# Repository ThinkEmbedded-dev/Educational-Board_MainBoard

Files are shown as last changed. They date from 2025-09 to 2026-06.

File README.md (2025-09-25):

# ThinkEmbeded Base Sensor Board
The ThinkEmbeded Base Sensor Board is a versatile sensor board designed for various embedded applications. 
It features multiple sensors, including temperature, humidity, light, accelerometer, and more, making it ideal for IoT projects, environmental monitoring, and data logging.

## Features
- Multiple integrated sensors (temperature, humidity, light, accelerometer, etc.)
- Compact and lightweight design
- Easy to interface with Nucleo boards
- Supports I2C and SPI external connections
- Onboard power regulation
- Extended by additional sheild for IoT connectivity and AI capabilities

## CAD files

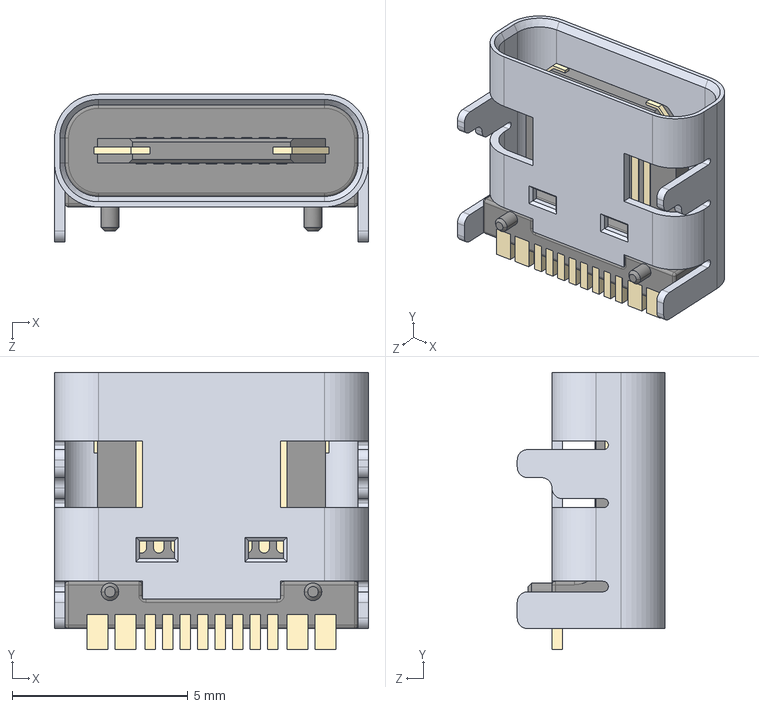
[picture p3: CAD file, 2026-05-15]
Libreries/3D Models/usb-c.STEP
8.94 x 7.90 x 4.20 mm

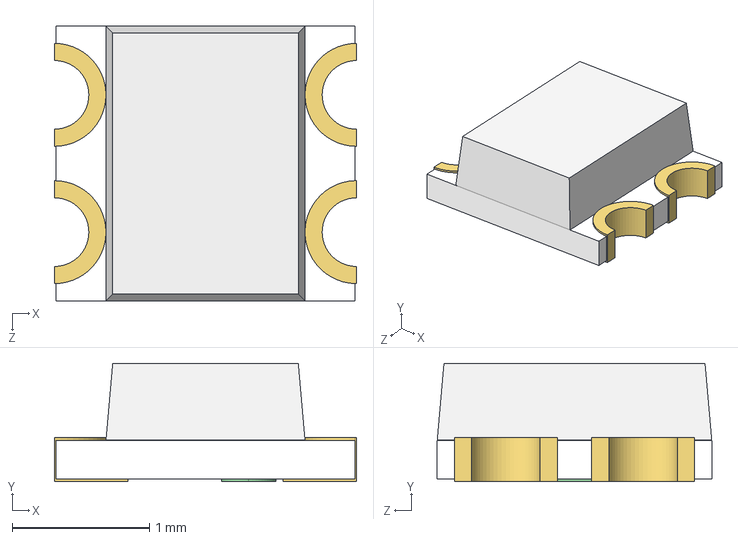
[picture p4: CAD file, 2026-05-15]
Libreries/3D Models/WS2812-2020.STEP
2.20 x 0.86 x 2.00 mm

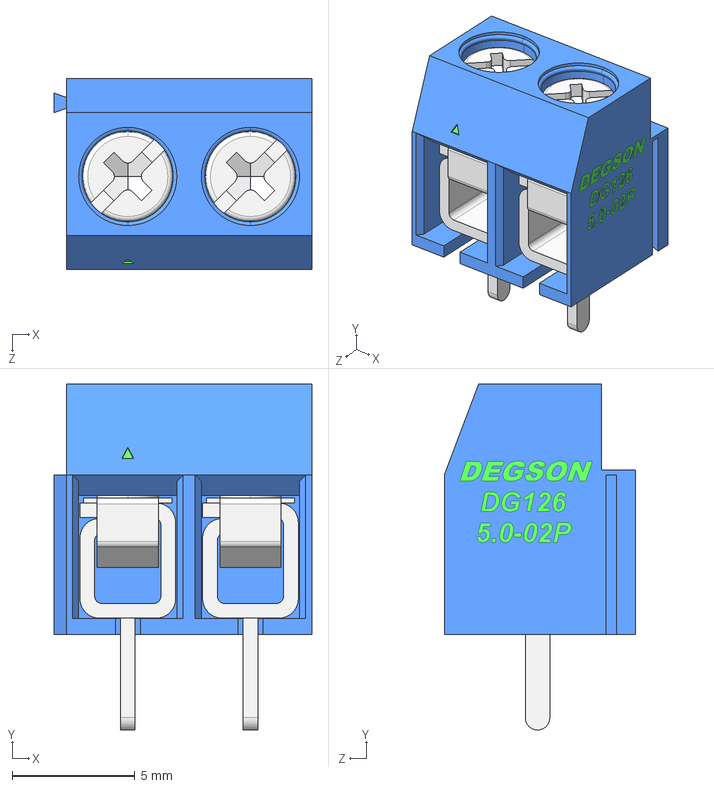
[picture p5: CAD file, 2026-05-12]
Libreries/3D Models/DG126-5.0-02P-12-00AH.STEP
10.5 x 14.1 x 7.80 mm

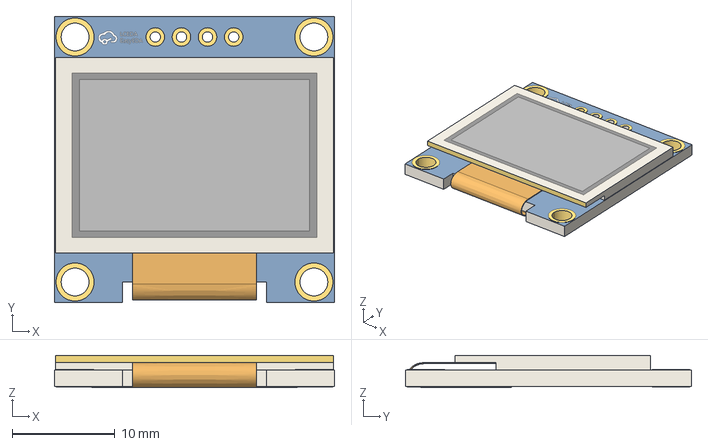
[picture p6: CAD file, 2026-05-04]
Libreries/3D Models/HS96L03W2C03 DISPLAY.step
27.2 x 27.8 x 3.12 mm

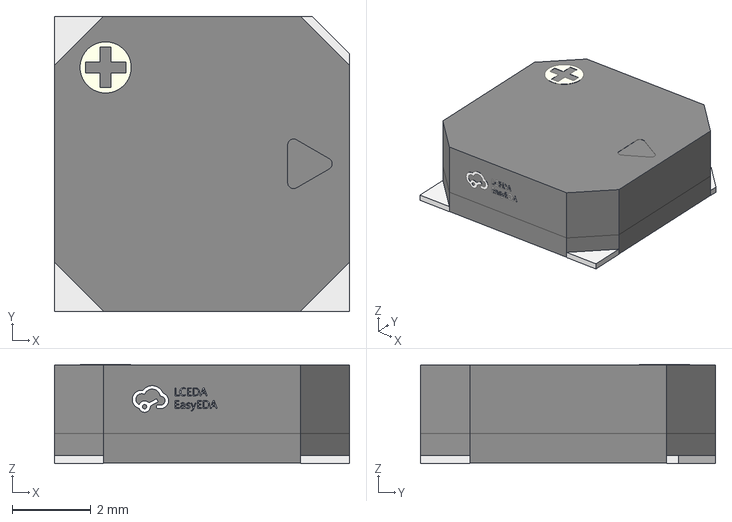
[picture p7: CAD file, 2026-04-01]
Libreries/3D Models/buzzer.step
7.50 x 7.51 x 2.52 mm

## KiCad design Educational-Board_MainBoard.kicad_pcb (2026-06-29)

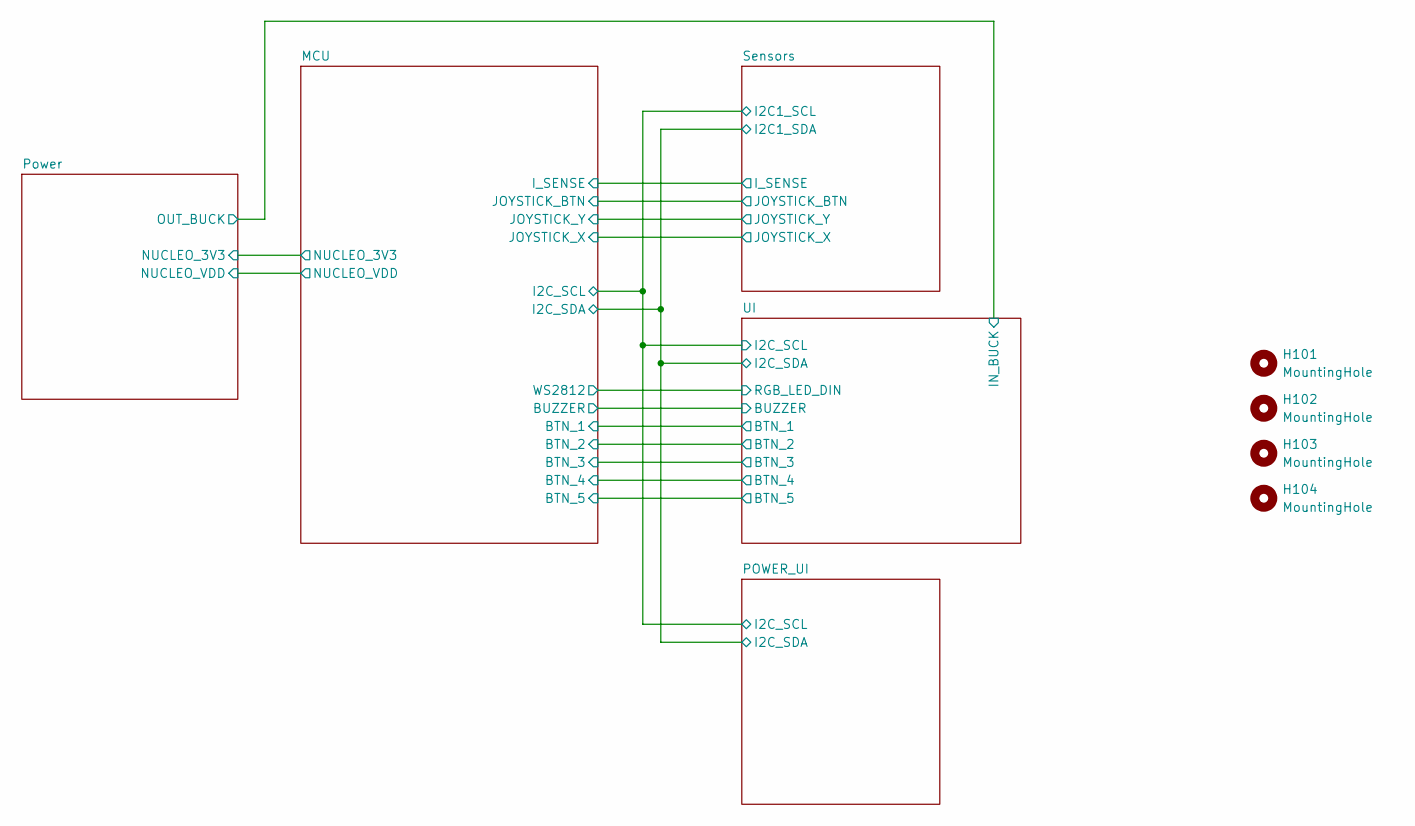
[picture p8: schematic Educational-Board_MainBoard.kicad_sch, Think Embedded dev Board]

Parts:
H101, H102, H103, H104: MountingHole; MountingHole_3.2mm_M3_ISO14580

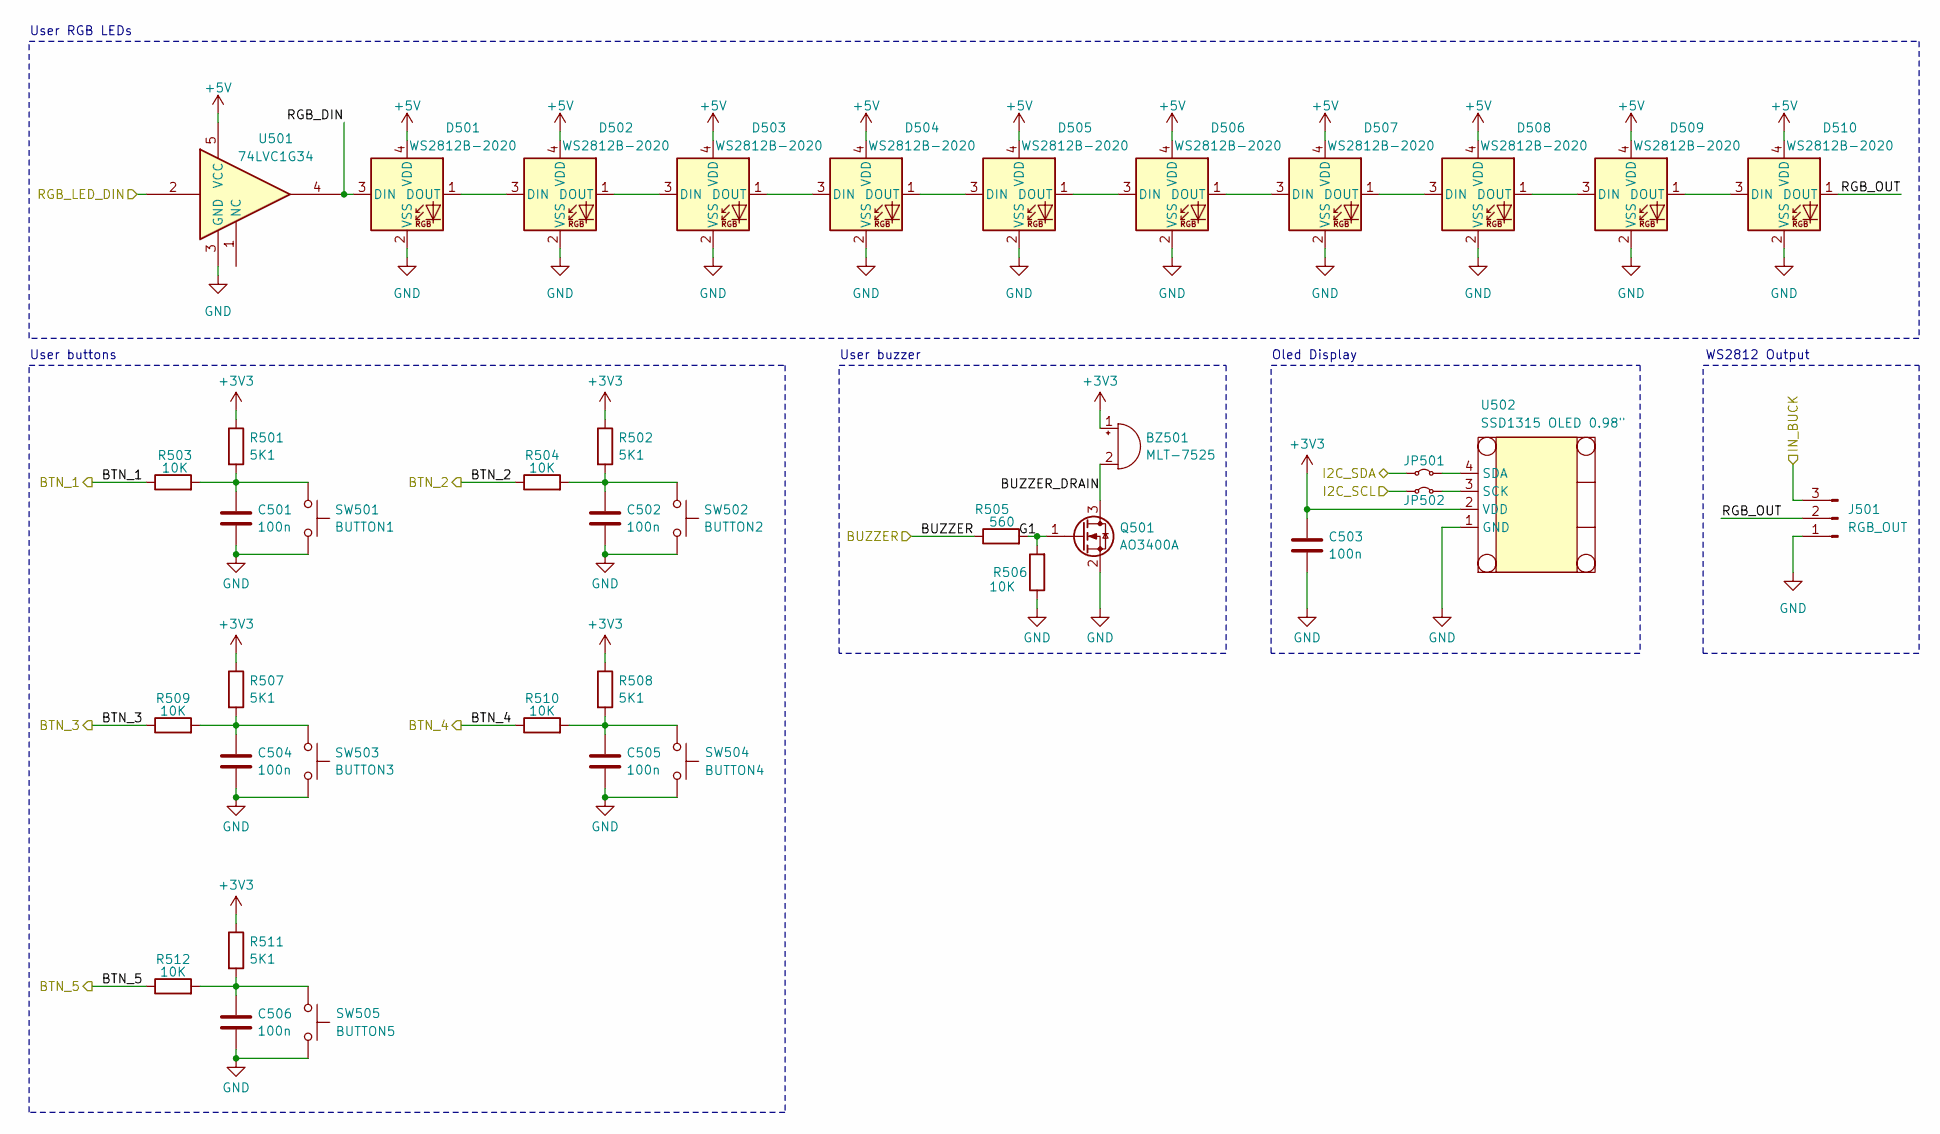
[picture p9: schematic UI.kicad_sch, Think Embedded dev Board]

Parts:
BZ501: MLT-7525; MLT-8530; LCSC C95299
C501, C502, C503, C504, C505, C506: 100n; C_0603_1608Metric_Pad1.08x0.95mm_HandSolder; LCSC C14663
D501, D502, D503, D504, D505, D506, D507, D508, D509, D510: WS2812B-2020; LED_WS2812B-2020_PLCC4_2.0x2.0mm; LCSC C965555
J501: RGB_OUT; PinHeader_1x03_P2.54mm_Vertical; LCSC C492402
JP501, JP502: 0R; R_0603_1608Metric_Pad0.98x0.95mm_HandSolder; LCSC C21189
Q501: AO3400A; SOT-23; LCSC C5380685
R501, R502, R507, R508, R511: 5K1; R_0603_1608Metric_Pad0.98x0.95mm_HandSolder; LCSC C23186
R503, R504, R506, R509, R510, R512: 10K; R_0603_1608Metric_Pad0.98x0.95mm_HandSolder; LCSC C25804
R505: 560; R_0603_1608Metric_Pad0.98x0.95mm_HandSolder; LCSC C23204
SW501: BUTTON1; SW_Push_1P1T_NO_CK_PTS125Sx43SMTR; LCSC C455223
SW502: BUTTON2; SW_Push_1P1T_NO_CK_PTS125Sx43SMTR; LCSC C455223
SW503: BUTTON3; SW_Push_1P1T_NO_CK_PTS125Sx43SMTR; LCSC C455223
SW504: BUTTON4; SW_Push_1P1T_NO_CK_PTS125Sx43SMTR; LCSC C455223
SW505: BUTTON5; SW_Push_1P1T_NO_CK_PTS125Sx43SMTR; LCSC C455223
U501: 74LVC1G34; SOT-23-5; LCSC C42380693
U502: SSD1315 OLED 0.98"; SSD1306; LCSC C5248080

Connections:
+3V3: BZ501.1 (+), C503.1, R501.1, R502.1, R507.1, R508.1, R511.1, U502.2 (VDD); also elsewhere on the board
+5V: D501.4 (VDD), D502.4 (VDD), D503.4 (VDD), D504.4 (VDD), D505.4 (VDD), D506.4 (VDD), D507.4 (VDD), D508.4 (VDD), D509.4 (VDD), D510.4 (VDD), U501.5 (VCC); also elsewhere on the board
/MCU/BTN_1: R503.1; also elsewhere on the board
/MCU/BTN_2: R504.1; also elsewhere on the board
/MCU/BTN_3: R509.1; also elsewhere on the board
/MCU/BTN_4: R510.1; also elsewhere on the board
/MCU/BTN_5: R512.1; also elsewhere on the board
/MCU/I2C_SCL: JP502.1 (A); also elsewhere on the board
/MCU/I2C_SDA: JP501.1 (A); also elsewhere on the board
/MCU/WS2812: U501.2; also elsewhere on the board
/Power/OUT_BUCK: J501.3; also elsewhere on the board
/UI/BUZZER: R505.1; also elsewhere on the board
/UI/BUZZER_DRAIN: BZ501.2 (-), Q501.3 (D)
/UI/G1: Q501.1 (G), R505.2, R506.2
/UI/RGB_DIN: D501.3 (DIN), U501.4
/UI/RGB_OUT: D510.1 (DOUT), J501.2
GND: C501.2, C502.2, C503.2, C504.2, C505.2, C506.2, D501.2 (VSS), D502.2 (VSS), D503.2 (VSS), D504.2 (VSS), D505.2 (VSS), D506.2 (VSS), D507.2 (VSS), D508.2 (VSS), D509.2 (VSS), D510.2 (VSS), J501.1, Q501.2 (S), R506.1, SW501.2, SW502.2, SW503.2, SW504.2, SW505.2, U501.3 (GND), U502.1 (GND); also elsewhere on the board
unnamed: C501.1, R501.2, R503.2, SW501.1
unnamed: C502.1, R502.2, R504.2, SW502.1
unnamed: C504.1, R507.2, R509.2, SW503.1
unnamed: C505.1, R508.2, R510.2, SW504.1
unnamed: C506.1, R511.2, R512.2, SW505.1
unnamed: D501.1 (DOUT), D502.3 (DIN)
unnamed: D502.1 (DOUT), D503.3 (DIN)
unnamed: D503.1 (DOUT), D504.3 (DIN)
unnamed: D504.1 (DOUT), D505.3 (DIN)
unnamed: D505.1 (DOUT), D506.3 (DIN)
unnamed: D506.1 (DOUT), D507.3 (DIN)
unnamed: D507.1 (DOUT), D508.3 (DIN)
unnamed: D508.1 (DOUT), D509.3 (DIN)
unnamed: D509.1 (DOUT), D510.3 (DIN)
unnamed: JP501.2 (B), U502.4 (SDA)
unnamed: JP502.2 (B), U502.3 (SCK)

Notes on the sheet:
WS2812 Output
Oled Display
User RGB LEDs
User buzzer
User buttons

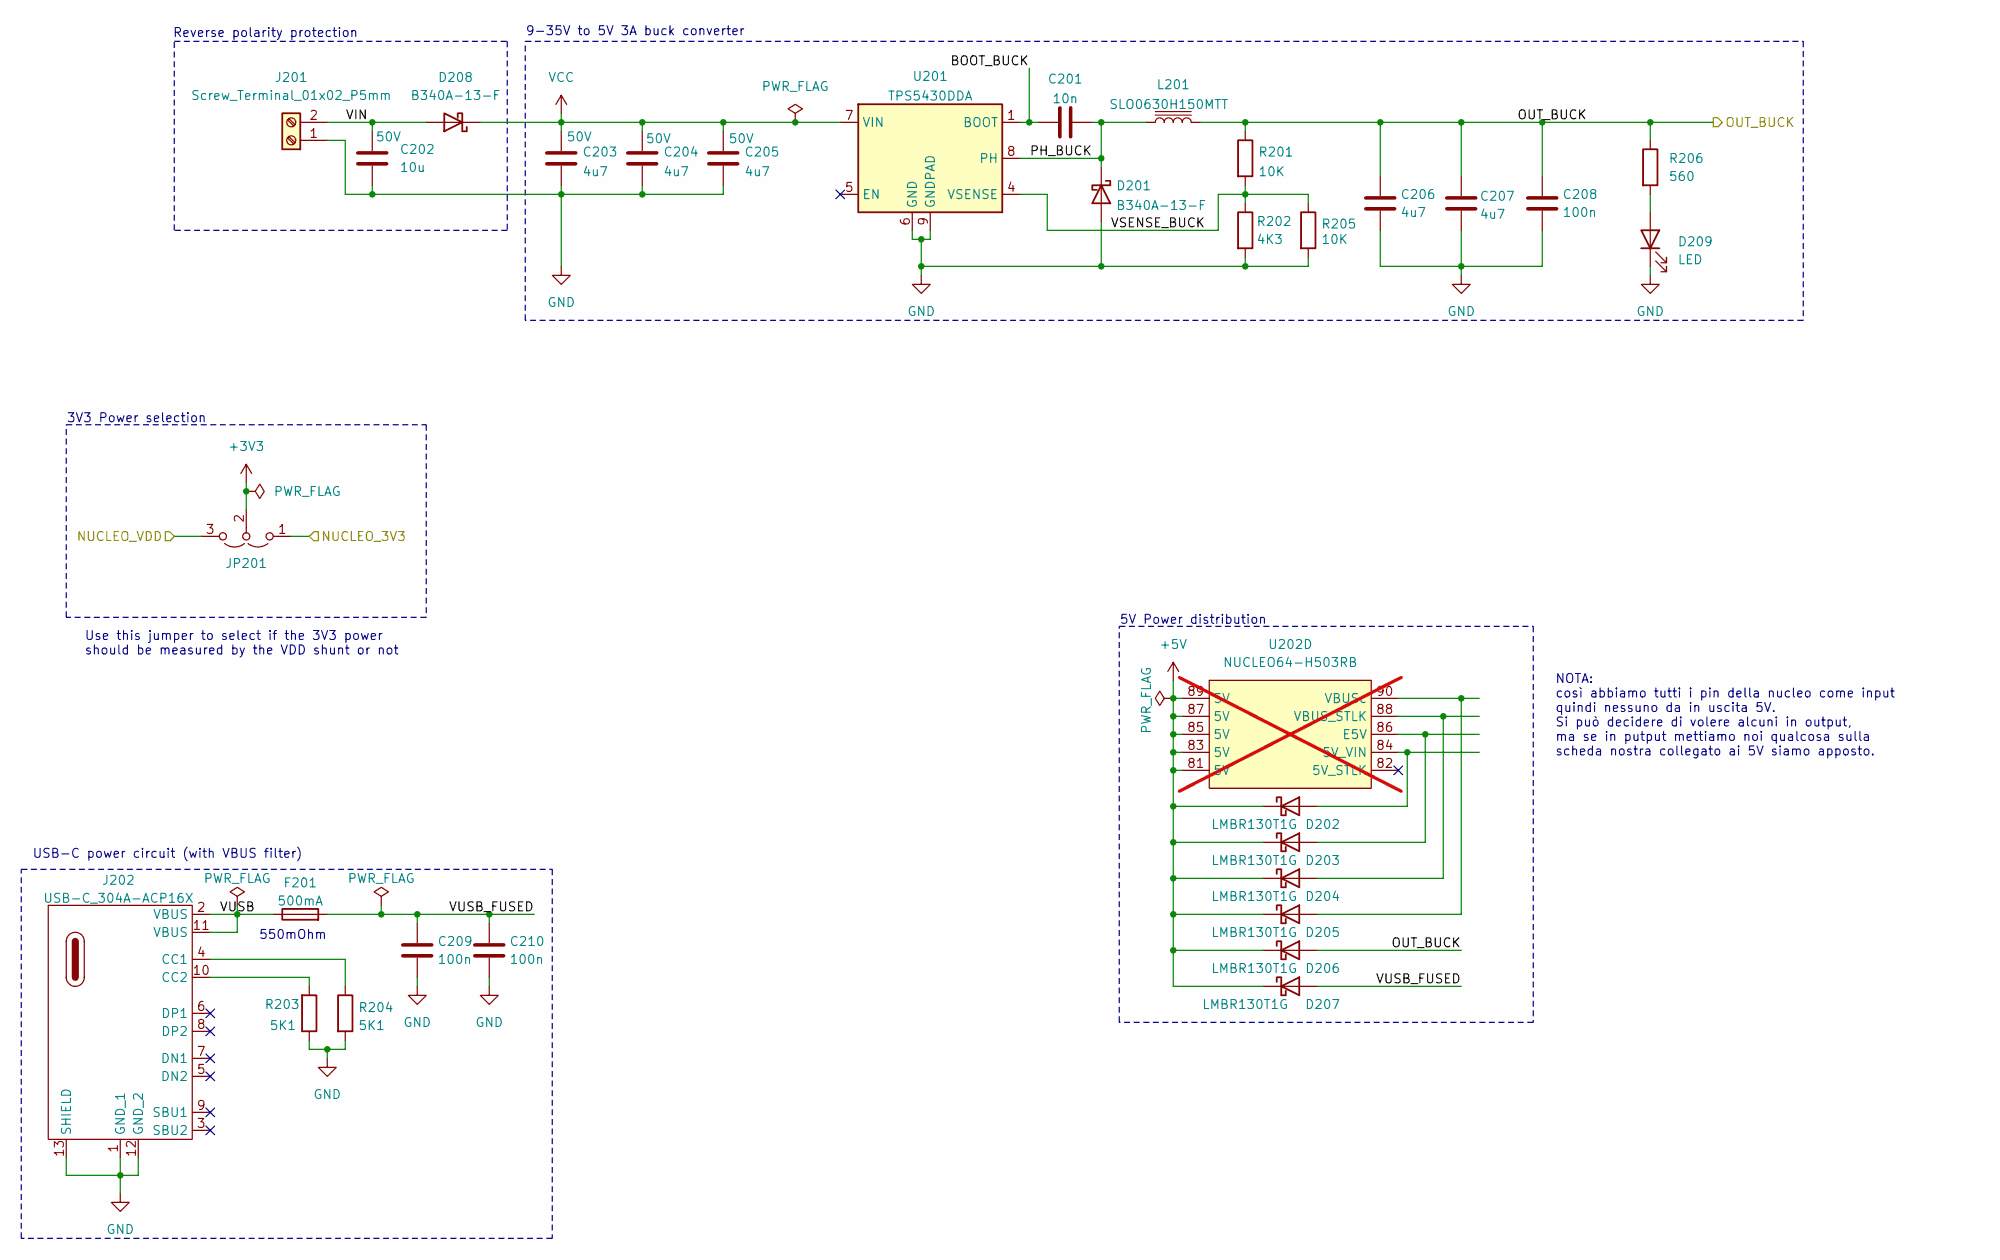
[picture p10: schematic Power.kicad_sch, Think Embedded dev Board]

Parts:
C201: 10n; C_0603_1608Metric_Pad1.08x0.95mm_HandSolder; LCSC C57112
C202: 10u; C_0603_1608Metric_Pad1.08x0.95mm_HandSolder; Voltage 50V; LCSC C19702
C203, C204, C205: 4u7; C_0603_1608Metric_Pad1.08x0.95mm_HandSolder; Voltage 50V; LCSC C19666
C206, C207: 4u7; C_0603_1608Metric_Pad1.08x0.95mm_HandSolder; LCSC C19666
C208, C209, C210: 100n; C_0603_1608Metric_Pad1.08x0.95mm_HandSolder; LCSC C14663
D201, D208: B340A-13-F; D_SMA; LCSC C85098
D202, D203, D204, D205, D206, D207: LMBR130T1G; D_SOD-123; LCSC C48974
D209: LED; LED_0603_1608Metric; LCSC C2290
F201: 500mA; Fuse_1206_3216Metric_Pad1.42x1.75mm_HandSolder; LCSC C151133
J201: Screw_Terminal_01x02_P5mm; TerminalBlock_MaiXu_MX126-5.0-02P_1x02_P5.00mm; LCSC C474881
J202: USB-C_304A-ACP16X; USB_C_304A-ACP16X; LCSC C2909610
JP201: Jumper_3_Open; PinHeader_1x03_P2.54mm_Vertical; LCSC C492402
L201: SLO0630H150MTT; L_AVX_LMLP07A7; LCSC C182182
R201, R205: 10K; R_0603_1608Metric_Pad0.98x0.95mm_HandSolder; LCSC C25804
R202: 4K3; R_0603_1608Metric_Pad0.98x0.95mm_HandSolder; LCSC C23159
R203, R204: 5K1; R_0603_1608Metric_Pad0.98x0.95mm_HandSolder; LCSC C23186
R206: 560; R_0603_1608Metric_Pad0.98x0.95mm_HandSolder; LCSC C23204
U201: TPS5430DDA; TI_SO-PowerPAD-8_ThermalVias; LCSC C9864
U202: NUCLEO64-H503RB; Nucleo64_ST-Morpho; not fitted

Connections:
+3V3: JP201.2 (C); also elsewhere on the board
+5V: D202.1 (K), D203.1 (K), D204.1 (K), D205.1 (K), D206.1 (K), D207.1 (K), U202.81 (5V), U202.83 (5V), U202.85 (5V), U202.87 (5V), U202.89 (5V); also elsewhere on the board
/MCU/NUCLEO_3V3: JP201.1 (A); also elsewhere on the board
/MCU/NUCLEO_VDD: JP201.3 (B); also elsewhere on the board
/Power/BOOT_BUCK: C201.1, U201.1 (BOOT)
/Power/OUT_BUCK: C206.1, C207.1, C208.1, D206.2 (A), L201.2, R201.1, R206.1; also elsewhere on the board
/Power/PH_BUCK: C201.2, D201.1 (K), L201.1, U201.8 (PH)
/Power/VIN: C202.1, D208.2 (A), J201.2
/Power/VSENSE_BUCK: R201.2, R202.1, R205.1, U201.4 (VSENSE)
/Power/VUSB: F201.1, J202.2 (VBUS), J202.11 (VBUS)
/Power/VUSB_FUSED: C209.1, C210.1, D207.2 (A), F201.2
GND: C202.2, C203.2, C204.2, C205.2, C206.2, C207.2, C208.2, C209.2, C210.2, D201.2 (A), D209.1 (K), J201.1, J202.1 (GND_1), J202.12 (GND_2), J202.13 (SHIELD), R202.2, R203.1, R204.2, R205.2, U201.6 (GND), U201.9 (GNDPAD); also elsewhere on the board
unnamed: D202.2 (A), U202.84 (5V_VIN)
unnamed: D203.2 (A), U202.86 (E5V)
unnamed: D204.2 (A), U202.88 (VBUS_STLK)
unnamed: D205.2 (A), U202.90 (VBUSc)
unnamed: D209.2 (A), R206.2
unnamed: J202.4 (CC1), R204.1
unnamed: J202.10 (CC2), R203.2
VCC: C203.1, C204.1, C205.1, D208.1 (K), U201.7 (VIN)

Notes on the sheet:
Use this jumper to select if the 3V3 power should be measured by the VDD shunt or not
5V Power distribution
550mOhm
9-35V to 5V 3A buck converter
Reverse polarity protection
USB-C power circuit (with VBUS filter)
3V3 Power selection
NOTA: così abbiamo tutti i pin della nucleo come input quindi nessuno da in uscita 5V. Si può decidere di volere alcuni in output, ma se in putput mettiamo noi qualcosa sulla scheda nostra collegato ai 5V siamo apposto.

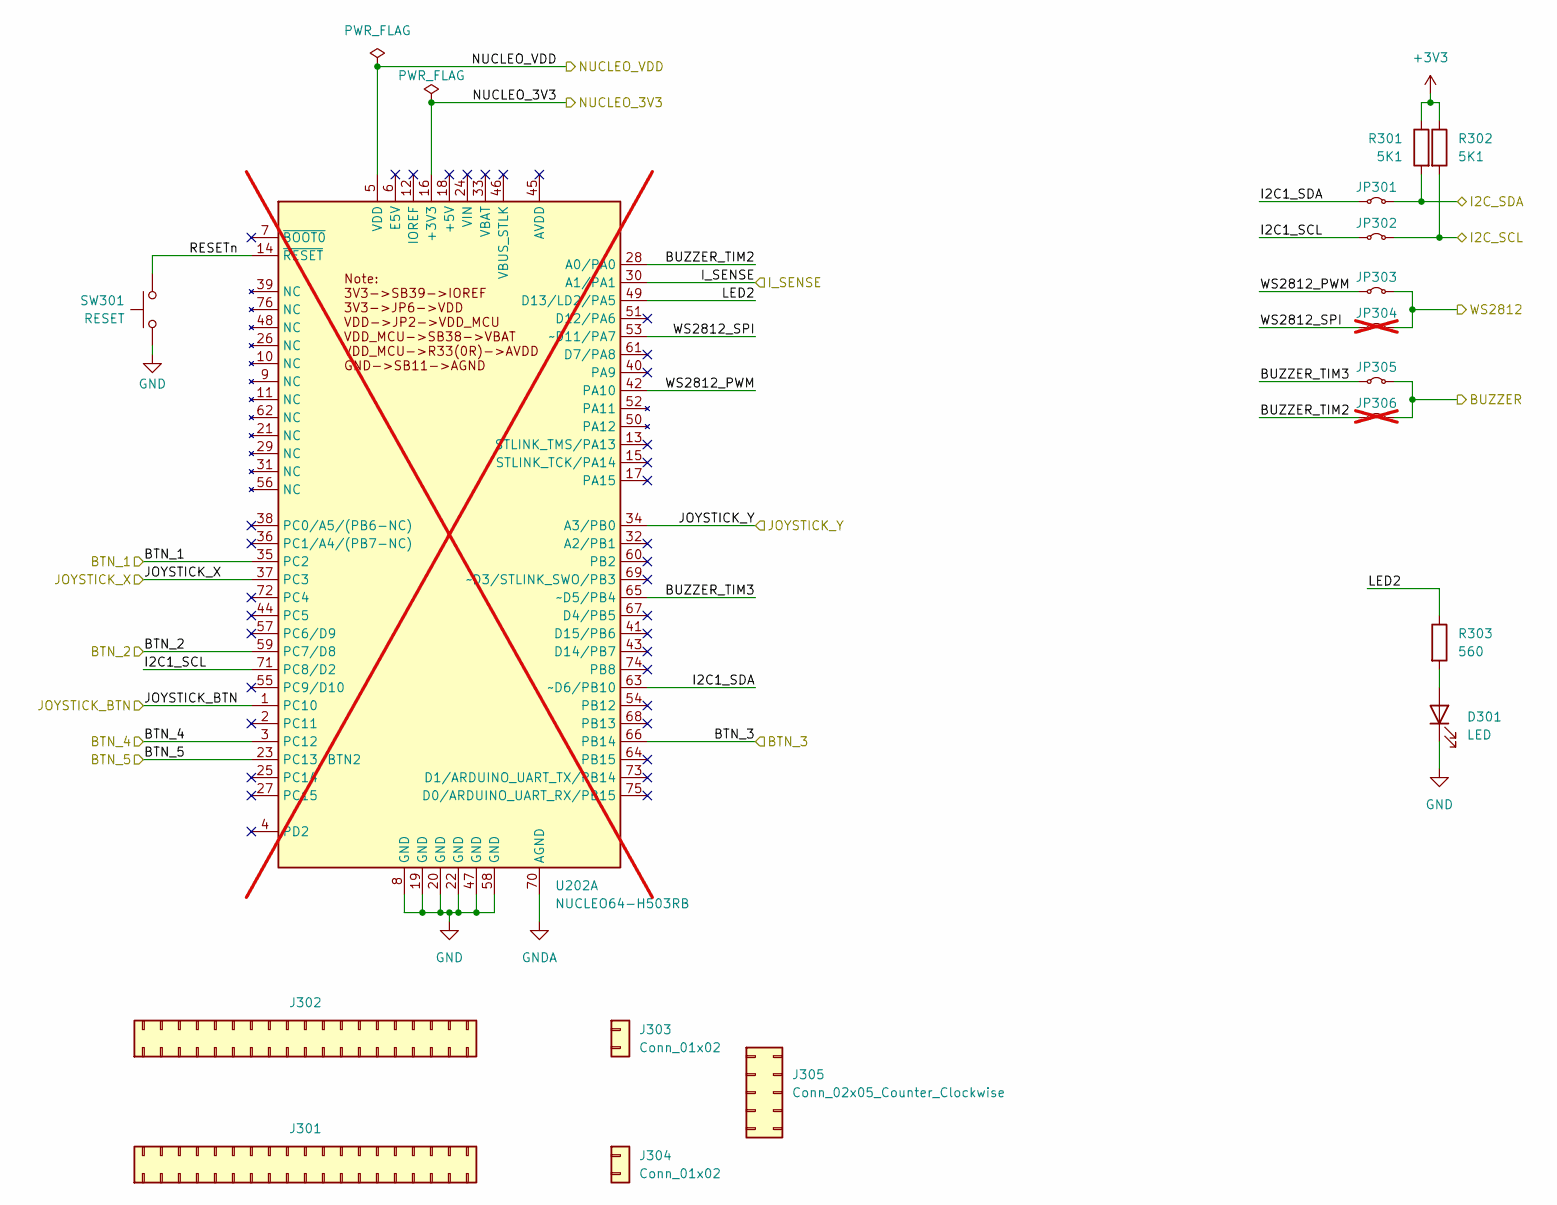
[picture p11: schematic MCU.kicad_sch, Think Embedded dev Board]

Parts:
D301: LED; LED_0603_1608Metric; LCSC C2290
J301, J302: Conn_02x20_Counter_Clockwise; PLACEHOLDER_PinSocket_2x19_P2.54mm_Vertical; LCSC C2977589
J303, J304: Conn_01x02; PLACEHOLDER_PinSocket_1x02_P2.54mm_Vertical; LCSC C492401
J305: Conn_02x05_Counter_Clockwise; PLACEHOLDER_PinSocket_2x05_P2.54mm_Vertical; LCSC C92270
JP301, JP302, JP303, JP305: 0R; R_0603_1608Metric_Pad0.98x0.95mm_HandSolder; LCSC C21189
JP304, JP306: 0R; R_0603_1608Metric_Pad0.98x0.95mm_HandSolder; LCSC C21189; not fitted
R301, R302: 5K1; R_0603_1608Metric_Pad0.98x0.95mm_HandSolder; LCSC C23186
R303: 560; R_0603_1608Metric_Pad0.98x0.95mm_HandSolder; LCSC C23204
SW301: RESET; SW_SPST_SKQG_WithoutStem; LCSC C455108
U202: NUCLEO64-H503RB; Nucleo64; not fitted

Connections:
+3V3: R301.1, R302.1; also elsewhere on the board
/MCU/BTN_1: U202.35 (PC2); also elsewhere on the board
/MCU/BTN_2: U202.59 (PC7); also elsewhere on the board
/MCU/BTN_3: U202.66 (PB14); also elsewhere on the board
/MCU/BTN_4: U202.3 (PC12); also elsewhere on the board
/MCU/BTN_5: U202.23 (PC13/BTN2); also elsewhere on the board
/MCU/BUZZER_TIM2: JP306.1 (A), U202.28 (PA0)
/MCU/BUZZER_TIM3: JP305.1 (A), U202.65 (PB4)
/MCU/I2C1_SCL: JP302.1 (A), U202.71 (PC8)
/MCU/I2C1_SDA: JP301.1 (A), U202.63 (PB10)
/MCU/I2C_SCL: JP302.2 (B), R302.2; also elsewhere on the board
/MCU/I2C_SDA: JP301.2 (B), R301.2; also elsewhere on the board
/MCU/I_SENSE: U202.30 (PA1); also elsewhere on the board
/MCU/JOYSTICK_BTN: U202.1 (PC10); also elsewhere on the board
/MCU/JOYSTICK_X: U202.37 (PC3); also elsewhere on the board
/MCU/JOYSTICK_Y: U202.34 (PB0); also elsewhere on the board
/MCU/LED2: R303.1, U202.49 (LD2/PA5)
/MCU/NUCLEO_3V3: U202.16 (+3V3); also elsewhere on the board
/MCU/NUCLEO_VDD: U202.5 (VDD); also elsewhere on the board
/MCU/RESETn: SW301.1, U202.14 (~RESET)
/MCU/WS2812: JP303.2 (B), JP304.2 (B); also elsewhere on the board
/MCU/WS2812_PWM: JP303.1 (A), U202.42 (PA10)
/MCU/WS2812_SPI: JP304.1 (A), U202.53 (PA7)
/UI/BUZZER: JP305.2 (B), JP306.2 (B); also elsewhere on the board
GND: D301.1 (K), SW301.2, U202.8 (GND), U202.19 (GND), U202.20 (GND), U202.22 (GND), U202.47 (GND), U202.58 (GND); also elsewhere on the board
GNDA: U202.70 (AGND)
unnamed: D301.2 (A), R303.2

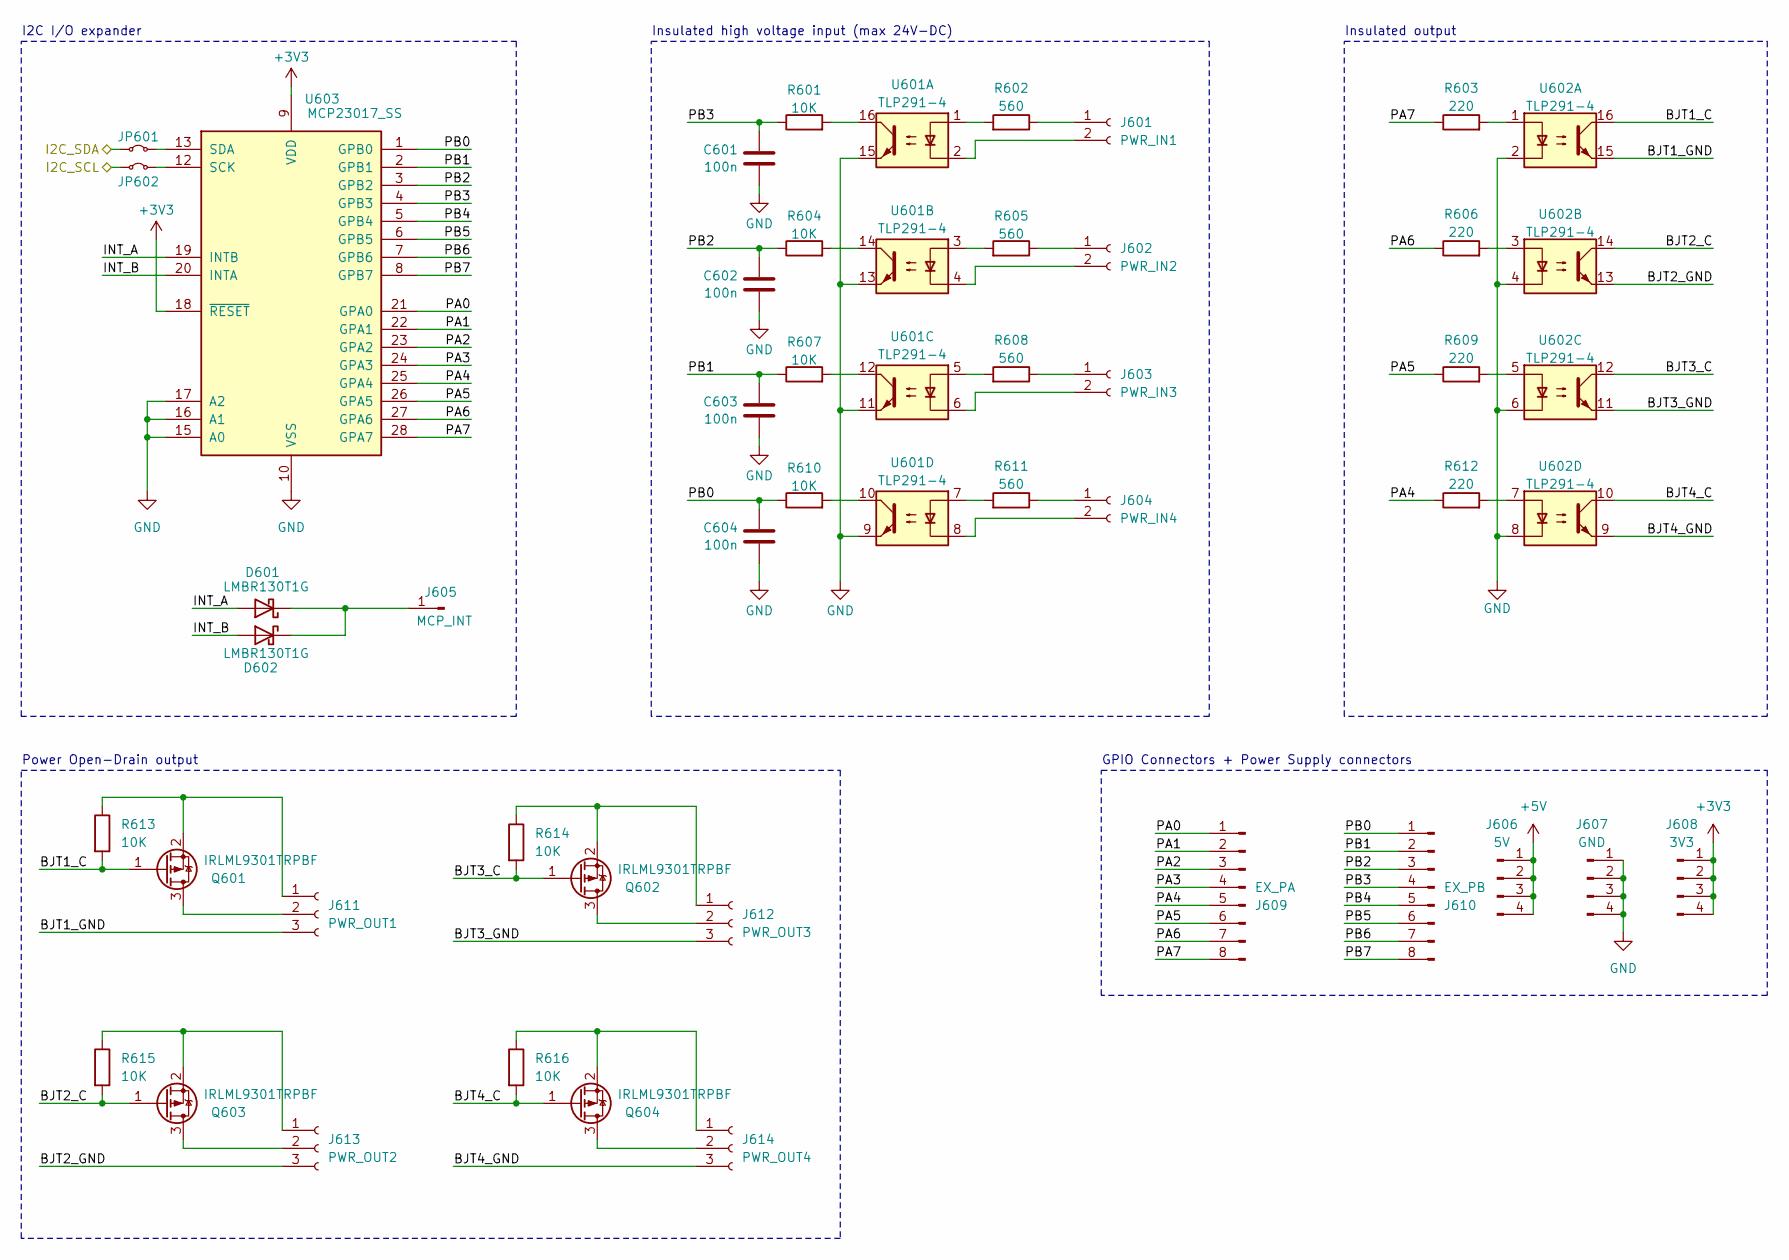
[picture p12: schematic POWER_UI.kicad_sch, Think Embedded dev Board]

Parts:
C601, C602, C603, C604: 100n; C_0603_1608Metric_Pad1.08x0.95mm_HandSolder; LCSC C14663
D601, D602: LMBR130T1G; D_SOD-123; LCSC C48974
J601: PWR_IN1; PinHeader_1x02_P2.54mm_Vertical; LCSC C492401
J602: PWR_IN2; PinHeader_1x02_P2.54mm_Vertical; LCSC C492401
J603: PWR_IN3; PinHeader_1x02_P2.54mm_Vertical; LCSC C492401
J604: PWR_IN4; PinHeader_1x02_P2.54mm_Vertical; LCSC C492401
J605: MCP_INT; PinHeader_1x01_P2.54mm_Vertical; LCSC C492400
J606: 5V; PinHeader_1x04_P2.54mm_Vertical; LCSC C492403
J607: GND; PinHeader_1x04_P2.54mm_Vertical; LCSC C492403
J608: 3V3; PinHeader_1x04_P2.54mm_Vertical; LCSC C492403
J609: EX_PA; PinHeader_1x08_P2.54mm_Vertical; LCSC C492407
J610: EX_PB; PinHeader_1x08_P2.54mm_Vertical; LCSC C492407
J611: PWR_OUT1; PinHeader_1x03_P2.54mm_Vertical; LCSC C492402
J612: PWR_OUT3; PinHeader_1x03_P2.54mm_Vertical; LCSC C492402
J613: PWR_OUT2; PinHeader_1x03_P2.54mm_Vertical; LCSC C492402
J614: PWR_OUT4; PinHeader_1x03_P2.54mm_Vertical; LCSC C492402
JP601, JP602: 0R; R_0603_1608Metric_Pad0.98x0.95mm_HandSolder; LCSC C21189
Q601, Q602, Q603, Q604: IRLML9301TRPBF; SOT-23; LCSC C82056
R601, R604, R607, R610, R613, R614, R615, R616: 10K; R_0603_1608Metric_Pad0.98x0.95mm_HandSolder; LCSC C25804
R602, R605, R608, R611: 560; R_0603_1608Metric_Pad0.98x0.95mm_HandSolder; LCSC C23204
R603, R606, R609, R612: 220; R_0603_1608Metric_Pad0.98x0.95mm_HandSolder; LCSC C22962
U601, U602: TLP291-4; SOP-16_4.4x10.4mm_P1.27mm; LCSC C60900
U603: MCP23017_SS; SSOP-28_5.3x10.2mm_P0.65mm; LCSC C506653

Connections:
+3V3: J608.1, J608.2, J608.3, J608.4, U603.9 (VDD), U603.18 (~RESET); also elsewhere on the board
+5V: J606.1, J606.2, J606.3, J606.4; also elsewhere on the board
/MCU/I2C_SCL: JP602.1 (A); also elsewhere on the board
/MCU/I2C_SDA: JP601.1 (A); also elsewhere on the board
/POWER_UI/BJT1_C: Q601.1 (G), R613.2, U602.16
/POWER_UI/BJT1_GND: J611.3, U602.15
/POWER_UI/BJT2_C: Q603.1 (G), R615.2, U602.14
/POWER_UI/BJT2_GND: J613.3, U602.13
/POWER_UI/BJT3_C: Q602.1 (G), R614.2, U602.12
/POWER_UI/BJT3_GND: J612.3, U602.11
/POWER_UI/BJT4_C: Q604.1 (G), R616.2, U602.10
/POWER_UI/BJT4_GND: J614.3, U602.9
/POWER_UI/INT_A: D601.2 (A), U603.19 (INTB)
/POWER_UI/INT_B: D602.2 (A), U603.20 (INTA)
/POWER_UI/PA0: J609.1, U603.21 (GPA0)
/POWER_UI/PA1: J609.2, U603.22 (GPA1)
/POWER_UI/PA2: J609.3, U603.23 (GPA2)
/POWER_UI/PA3: J609.4, U603.24 (GPA3)
/POWER_UI/PA4: J609.5, R612.1, U603.25 (GPA4)
/POWER_UI/PA5: J609.6, R609.1, U603.26 (GPA5)
/POWER_UI/PA6: J609.7, R606.1, U603.27 (GPA6)
/POWER_UI/PA7: J609.8, R603.1, U603.28 (GPA7)
/POWER_UI/PB0: C604.1, J610.1, R610.1, U603.1 (GPB0)
/POWER_UI/PB1: C603.1, J610.2, R607.1, U603.2 (GPB1)
/POWER_UI/PB2: C602.1, J610.3, R604.1, U603.3 (GPB2)
/POWER_UI/PB3: C601.1, J610.4, R601.1, U603.4 (GPB3)
/POWER_UI/PB4: J610.5, U603.5 (GPB4)
/POWER_UI/PB5: J610.6, U603.6 (GPB5)
/POWER_UI/PB6: J610.7, U603.7 (GPB6)
/POWER_UI/PB7: J610.8, U603.8 (GPB7)
GND: C601.2, C602.2, C603.2, C604.2, J607.1, J607.2, J607.3, J607.4, U601.9, U601.11, U601.13, U601.15, U602.2, U602.4, U602.6, U602.8, U603.10 (VSS), U603.15 (A0), U603.16 (A1), U603.17 (A2); also elsewhere on the board
unnamed: D601.1 (K), D602.1 (K), J605.1
unnamed: J601.1, R602.1
unnamed: J601.2, U601.2
unnamed: J602.1, R605.1
unnamed: J602.2, U601.4
unnamed: J603.1, R608.1
unnamed: J603.2, U601.6
unnamed: J604.1, R611.1
unnamed: J604.2, U601.8
unnamed: J611.1, Q601.2 (S), R613.1
unnamed: J611.2, Q601.3 (D)
unnamed: J612.1, Q602.2 (S), R614.1
unnamed: J612.2, Q602.3 (D)
unnamed: J613.1, Q603.2 (S), R615.1
unnamed: J613.2, Q603.3 (D)
unnamed: J614.1, Q604.2 (S), R616.1
unnamed: J614.2, Q604.3 (D)
unnamed: JP601.2 (B), U603.13 (SDA)
unnamed: JP602.2 (B), U603.12 (SCK)
unnamed: R601.2, U601.16
unnamed: R602.2, U601.1
unnamed: R603.2, U602.1
unnamed: R604.2, U601.14
unnamed: R605.2, U601.3
unnamed: R606.2, U602.3
unnamed: R607.2, U601.12
unnamed: R608.2, U601.5
unnamed: R609.2, U602.5
unnamed: R610.2, U601.10
unnamed: R611.2, U601.7
unnamed: R612.2, U602.7

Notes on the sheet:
Insulated output
Insulated high voltage input (max 24V-DC)
I2C I/O expander
Power Open-Drain output
GPIO Connectors + Power Supply connectors

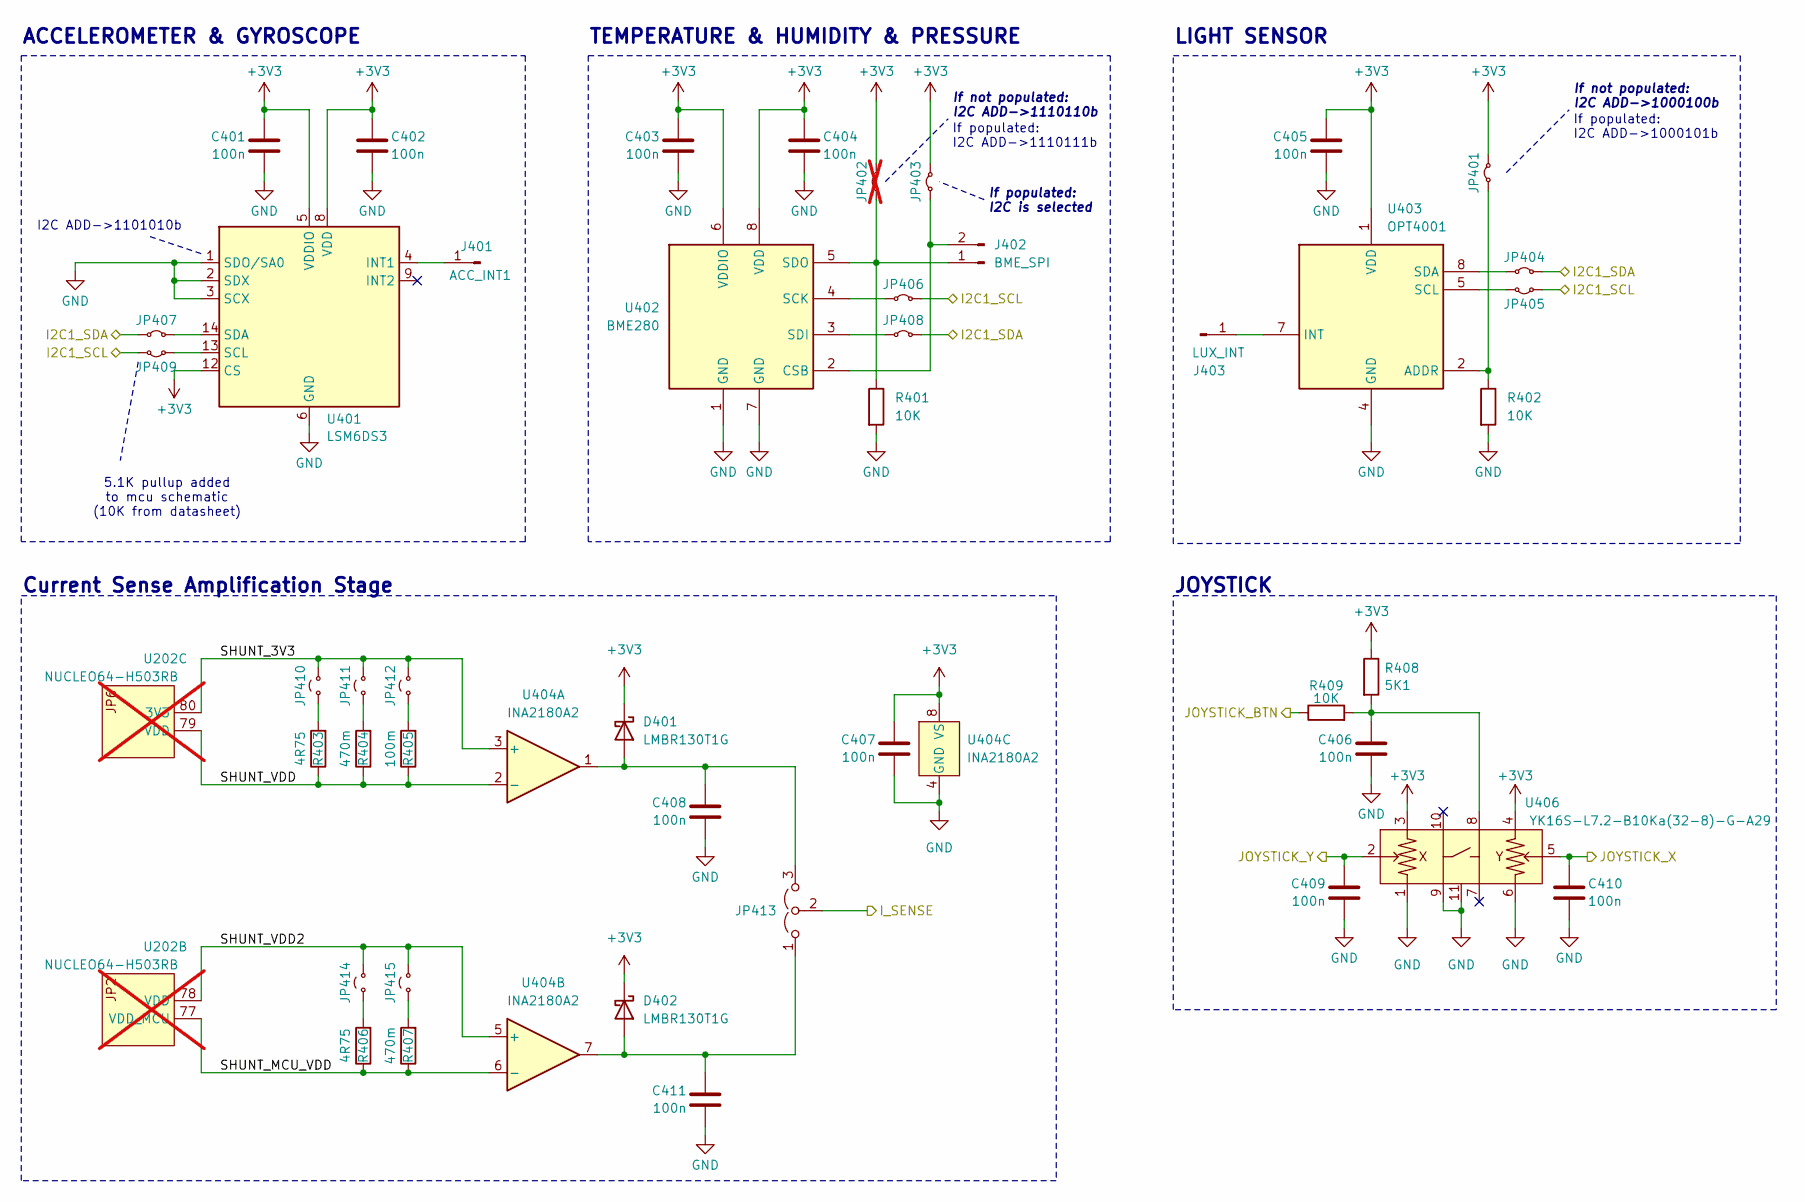
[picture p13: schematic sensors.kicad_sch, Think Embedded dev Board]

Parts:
C401, C402, C403, C404, C405, C406, C407, C408, C409, C410, C411: 100n; C_0603_1608Metric_Pad1.08x0.95mm_HandSolder; LCSC C14663
D401, D402: LMBR130T1G; D_SOD-123; LCSC C48974
J401: ACC_INT1; PinHeader_1x01_P2.54mm_Vertical; LCSC C492400
J402: BME_SPI; PinHeader_1x02_P2.54mm_Vertical; LCSC C492401
J403: LUX_INT; PinHeader_1x01_P2.54mm_Vertical; LCSC C492400
JP401, JP403, JP404, JP405, JP406, JP407, JP408, JP409: 0R; R_0603_1608Metric_Pad0.98x0.95mm_HandSolder; LCSC C21189
JP402: 0R; R_0603_1608Metric_Pad0.98x0.95mm_HandSolder; LCSC C21189; not fitted
JP410, JP411, JP412, JP414, JP415: Jumper_2_Small_Open; PinHeader_1x02_P2.54mm_Vertical; LCSC C492401
JP413: Jumper_3_Open; PinHeader_1x03_P2.54mm_Vertical; LCSC C492402
R401, R402, R409: 10K; R_0603_1608Metric_Pad0.98x0.95mm_HandSolder; LCSC C25804
R403, R406: 4R75; R_0603_1608Metric_Pad0.98x0.95mm_HandSolder; LCSC C2090841
R404, R407: 470m; R_0603_1608Metric_Pad0.98x0.95mm_HandSolder; LCSC C3013349
R405: 100m; R_0603_1608Metric_Pad0.98x0.95mm_HandSolder; LCSC C3013345
R408: 5K1; R_0603_1608Metric_Pad0.98x0.95mm_HandSolder; LCSC C23186
U202: NUCLEO64-H503RB; Nucleo64_ST-Morpho; not fitted
U401: LSM6DS3; LGA-14_3x2.5mm_P0.5mm_LayoutBorder3x4y; LCSC C967633
U402: BME280; Bosch_LGA-8_2.5x2.5mm_P0.65mm_ClockwisePinNumbering; LCSC C92489
U403: OPT4001; SOT-583-8; LCSC C17612395
U404: INA2180A2; VSSOP-8_3x3mm_P0.65mm; LCSC C2058508
U406: YK16S-L7.2-B10Ka(32-8)-G-A29; LCSC C37323746

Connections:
+3V3: C401.1, C402.1, C403.1, C404.1, C405.1, C407.1, D401.1 (K), D402.1 (K), JP401.2 (B), JP402.2 (B), JP403.2 (B), R408.1, U401.5 (VDDIO), U401.8 (VDD), U401.12 (CS), U402.6 (VDDIO), U402.8 (VDD), U403.1 (VDD), U404.8 (VS), U406.3, U406.4; also elsewhere on the board
/MCU/I2C_SCL: JP405.2 (B), JP406.2 (B), JP409.2 (B); also elsewhere on the board
/MCU/I2C_SDA: JP404.2 (B), JP407.1 (A), JP408.2 (B); also elsewhere on the board
/MCU/I_SENSE: JP413.2 (C); also elsewhere on the board
/MCU/JOYSTICK_BTN: R409.1; also elsewhere on the board
/MCU/JOYSTICK_X: C410.1, U406.5; also elsewhere on the board
/MCU/JOYSTICK_Y: C409.1, U406.2; also elsewhere on the board
/Sensors/SHUNT_3V3: JP410.2 (B), JP411.2 (B), JP412.2 (B), U202.80 (3V3), U404.3 (+)
/Sensors/SHUNT_MCU_VDD: R406.1, R407.1, U202.77 (VDD_MCU), U404.6 (-)
/Sensors/SHUNT_VDD: R403.1, R404.1, R405.1, U202.79 (VDD), U404.2 (-)
/Sensors/SHUNT_VDD2: JP414.2 (B), JP415.2 (B), U202.78 (VDD), U404.5 (+)
GND: C401.2, C402.2, C403.2, C404.2, C405.2, C406.2, C407.2, C408.2, C409.2, C410.2, C411.2, R401.2, R402.2, U401.1 (SDO/SA0), U401.2 (SDX), U401.3 (SCX), U401.6 (GND), U401.7 (GND), U402.1 (GND), U402.7 (GND), U403.4 (GND), U404.4 (GND), U406.1, U406.6, U406.9, U406.11; also elsewhere on the board
unnamed: C406.1, R408.2, R409.2, U406.8
unnamed: C408.1, D401.2 (A), JP413.3 (B), U404.1
unnamed: C411.1, D402.2 (A), JP413.1 (A), U404.7
unnamed: J401.1, U401.4 (INT1)
unnamed: J402.1, JP402.1 (A), R401.1, U402.5 (SDO)
unnamed: J402.2, JP403.1 (A), U402.2 (CSB)
unnamed: J403.1, U403.7 (INT)
unnamed: JP401.1 (A), R402.1, U403.2 (ADDR)
unnamed: JP404.1 (A), U403.8 (SDA)
unnamed: JP405.1 (A), U403.5 (SCL)
unnamed: JP406.1 (A), U402.4 (SCK)
unnamed: JP407.2 (B), U401.14 (SDA)
unnamed: JP408.1 (A), U402.3 (SDI)
unnamed: JP409.1 (A), U401.13 (SCL)
unnamed: JP410.1 (A), R403.2
unnamed: JP411.1 (A), R404.2
unnamed: JP412.1 (A), R405.2
unnamed: JP414.1 (A), R406.2
unnamed: JP415.1 (A), R407.2

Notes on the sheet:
Current Sense Amplification Stage
If populated: I2C ADD->1000101b
ACCELEROMETER & GYROSCOPE
If populated: I2C ADD->1110111b
5.1K pullup added to mcu schematic (10K from datasheet)
If not populated: I2C ADD->1110110b
TEMPERATURE & HUMIDITY & PRESSURE
LIGHT SENSOR
JOYSTICK
I2C ADD->1101010b
If not populated: I2C ADD->1000100b
If populated: I2C is selected

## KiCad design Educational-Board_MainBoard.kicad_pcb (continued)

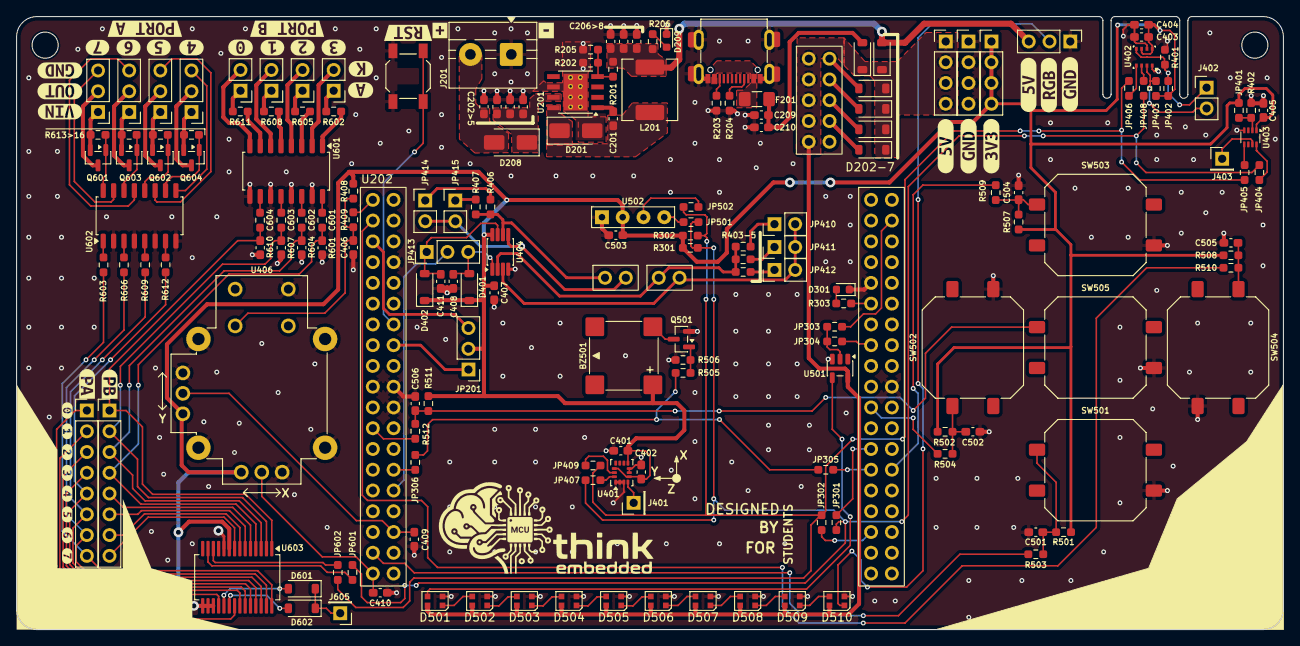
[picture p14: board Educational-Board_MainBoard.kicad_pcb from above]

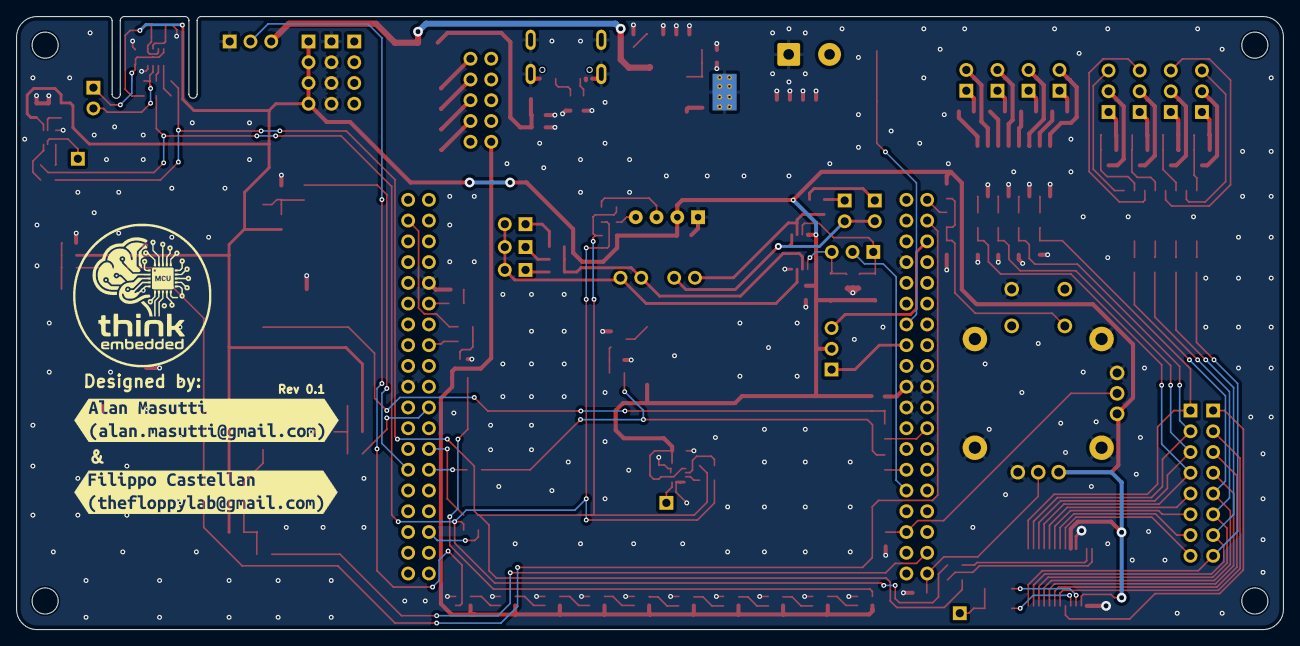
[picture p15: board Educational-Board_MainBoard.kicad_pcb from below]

Board: 2 copper layers, 155.0 x 75.0 mm, 218 parts (7 on the bottom side), 142 nets.

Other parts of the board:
kibuzzard-69F1C3A3: G***; kibuzzard-69F1C3A3
kibuzzard-69F1C3AE: G***; kibuzzard-69F1C3AE
kibuzzard-69F1C39D, kibuzzard-69F1C39D#2: G***; kibuzzard-69F1C39D
kibuzzard-69F1CCD6: G***; kibuzzard-69F1CCD6
kibuzzard-69F1CD88: G***; kibuzzard-69F1CD88
kibuzzard-69F3BF46: G***; kibuzzard-69F3BF46
kibuzzard-69F9D27B: G***; kibuzzard-69F9D27B
kibuzzard-69F9D252: G***; kibuzzard-69F9D252
kibuzzard-69F9F64C: G***; kibuzzard-69F9F64C
kibuzzard-69F9F66B: G***; kibuzzard-69F9F66B
kibuzzard-69F9F71E: G***; kibuzzard-69F9F71E
kibuzzard-69F9F605: G***; kibuzzard-69F9F605
kibuzzard-69F9F647: G***; kibuzzard-69F9F647
kibuzzard-69F9F651: G***; kibuzzard-69F9F651
kibuzzard-69F9F658: G***; kibuzzard-69F9F658
kibuzzard-69F9F712: G***; kibuzzard-69F9F712
kibuzzard-69F9F718: G***; kibuzzard-69F9F718
kibuzzard-69F9F723: G***; kibuzzard-69F9F723
kibuzzard-69F9F764: G***; kibuzzard-69F9F764
kibuzzard-69F2951E: G***; kibuzzard-69F2951E
kibuzzard-69FB5140: G***; kibuzzard-69FB5140
kibuzzard-69FCC61F: G***; kibuzzard-69FCC61F
kibuzzard-69FCC630: G***; kibuzzard-69FCC630
kibuzzard-69FCE76D: G***; kibuzzard-69FCE76D
kibuzzard-69FCE77B: G***; kibuzzard-69FCE77B
kibuzzard-69FCE77E: G***; kibuzzard-69FCE77E
kibuzzard-69FCE79E: G***; kibuzzard-69FCE79E
kibuzzard-69FCE761: G***; kibuzzard-69FCE761
kibuzzard-69FCE768: G***; kibuzzard-69FCE768
kibuzzard-69FCE770: G***; kibuzzard-69FCE770
kibuzzard-69FCE773: G***; kibuzzard-69FCE773
kibuzzard-69FCE777: G***; kibuzzard-69FCE777
kibuzzard-69FCE792: G***; kibuzzard-69FCE792
kibuzzard-69FCE911: G***; kibuzzard-69FCE911
kibuzzard-69FDFC10: G***; kibuzzard-69FDFC10

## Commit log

2025-09-29 Aggiunto nomi
    [Educational-Board_MainBoard.kicad_sch]
2026-01-11 Aggiunto schema generale alimentazione e UI. Da fare sourcing componenti
    [Educational-Board_MainBoard.kicad_sch, Power.kicad_sch, UI.kicad_sch]
2026-02-28 Sistemato disaccoppiamento pulasnti, e aggiunto gyro i2c
    [Educational-Board_MainBoard.kicad_sch, UI.kicad_sch, sensors.kicad_sch]
2026-02-28 Created the connectors footpint library + started Nucleo64 footprint
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2026-03-03 Added NUCLEO-H503RB symbol + created Nucleo64_ST_Morpho footprint
    - The footprint is created starting from Nucleo64 ones
    - The Nucleo Symbol is created and associated to the new footprint
2026-03-05 Added MCU sheet + added a button on the UI sheet
    [Educational-Board_MainBoard.kicad_sch, MCU.kicad_sch, UI.kicad_sch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]
2026-03-06 Connected the nucleo to local nets
    - I created all the local lables to the MCU schematic and connected them to the corresponding pins of the Nucleo board.
    - I renumed the hierarchical sheets to be in order of importance
    - I added solder jumpers for making the board more versatile in some cases
    - Corrected the Nucleo pinout on the schematic symbol
    [Educational-Board_MainBoard.kicad_sch, MCU.kicad_sch, Power.kicad_sch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]
2026-03-09 Added BME280 on Sensor sheet + Added Power frontend on the dedicated sheet + added I2C Resistors + minor changes
    [Educational-Board_MainBoard.kicad_sch, MCU.kicad_sch, POWER_UI.kicad_sch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]
2026-03-09 Small changes
    [MCU.kicad_sch, POWER_UI.kicad_sch, Power.kicad_sch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]
2026-03-09 Corrected nucleo symbol and footprint, Fixes #2
2026-03-09 Added Power connector of the nucleo to the schematic
    [MCU.kicad_sch, Power.kicad_sch]
2026-03-10 Added OPT4001 to schematic
    [sensors.kicad_sch]
2026-03-11 Added the hierarchical pins of the sheets and connected them, Fixes #7
    [Educational-Board_MainBoard.kicad_sch, MCU.kicad_sch, Power.kicad_sch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]
2026-03-12 Added Joystick, Fixes #8
    [sensors.kicad_sch]
2026-03-12 Added hierarchical lablels to schematic
    [Educational-Board_MainBoard.kicad_sch]
2026-03-12 fixed #1 , added protection circuit 5V selector jumper
    [Educational-Board_MainBoard.kicad_sch, MCU.kicad_sch, POWER_UI.kicad_sch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]
2026-03-18 Changed the grounding of the opto-coupled power stage + Added UI connectors + Removed a Diode on the Power Sheet (Fixes #3)
    [MCU.kicad_sch, POWER_UI.kicad_sch, Power.kicad_sch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]
2026-03-18 Completated the Power Schema + Added Shunts resistors with OP Amp + Connected the RGB Connector to the BUCK (Fixes #5)
    [Educational-Board_MainBoard.kicad_sch, MCU.kicad_sch, POWER_UI.kicad_sch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]
2026-03-18 Runned ERC for the first time and fixed some errors
    [MCU.kicad_sch, POWER_UI.kicad_sch, Power.kicad_sch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]
2026-03-18 Changed some value for grouping components
    Basically two resistors valued 5.1k and 5K1 have the same value
    [Power.kicad_sch, UI.kicad_sch, sensors.kicad_sch]
2026-03-21 Fixed some schematic issues
    [POWER_UI.kicad_sch, UI.kicad_sch, sensors.kicad_sch]
2026-03-25 Referenced the shematic and started the sourcing part
    [MCU.kicad_sch, POWER_UI.kicad_sch, Power.kicad_sch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]
2026-03-25 added some lcsc code
    [Power.kicad_sch]
2026-03-26 added some lcsc codes, changed reverse voltage protection with a diode
    [MCU.kicad_sch, POWER_UI.kicad_sch, Power.kicad_sch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]
2026-03-28 added some lcsc PN, and uniformed some resistors values to reduce BOM count
    [MCU.kicad_sch, POWER_UI.kicad_sch, Power.kicad_sch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]
2026-04-01 Created buzzer footprint, and fixed some libraries simbols and footprint
    [POWER_UI.kicad_sch, Power.kicad_sch, UI.kicad_sch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]
2026-04-01 Finished the sourcing of the components
    [MCU.kicad_sch, POWER_UI.kicad_sch, Power.kicad_sch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]
2026-04-01 Started the checking of the components
    [MCU.kicad_sch, POWER_UI.kicad_sch, Power.kicad_sch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]
2026-04-02 Continued to check components footprints
    [POWER_UI.kicad_sch, Power.kicad_sch, UI.kicad_sch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]
2026-04-22 Changed two connectors
    [MCU.kicad_sch, Power.kicad_sch, UI.kicad_sch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]
2026-04-22 Started the floorplan + added the Power LED
    [Educational-Board_MainBoard.kicad_pcb, Educational-Board_MainBoard.kicad_sch, MCU.kicad_sch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]
2026-04-23 Continued the floor plan
    [Educational-Board_MainBoard.kicad_pcb, Educational-Board_MainBoard.kicad_sch, POWER_UI.kicad_sch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]
2026-04-27 some placement
    [Educational-Board_MainBoard.kicad_pcb, Power.kicad_sch]
2026-04-27 Changed a bit the design, nothing important to note
    [Educational-Board_MainBoard.kicad_pcb]
2026-04-29 Fixed some errors on the SSD1306 footprint
2026-04-29 Added some netclasses + started routing of some small parts + reordered some groups
    [Educational-Board_MainBoard.kicad_pcb, Educational-Board_MainBoard.kicad_sch, POWER_UI.kicad_sch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]
2026-04-29 Finished the netclass assignment
    [Educational-Board_MainBoard.kicad_pcb]
2026-04-29 Routed the buck stage
    [Educational-Board_MainBoard.kicad_pcb]
2026-04-29 Updated the SSD1316 footprint
    [Educational-Board_MainBoard.kicad_pcb]
2026-04-30 Roued the majority of the nets of the POWER IO
    [Educational-Board_MainBoard.kicad_pcb, POWER_UI.kicad_sch, sensors.kicad_sch]
2026-04-30 Routed the another part of POWER_UI
    [Educational-Board_MainBoard.kicad_pcb]
2026-04-30 Continued routing + resized the board
    [Educational-Board_MainBoard.kicad_pcb, MCU.kicad_sch, sensors.kicad_sch]
2026-04-30 Some placing and routing
    Added joystick 3D model
    [Educational-Board_MainBoard.kicad_pcb, UI.kicad_sch, sensors.kicad_sch]
2026-05-04 fixed i2c swap bridge (to be checked if now are ok) routed bme280
    [Educational-Board_MainBoard.kicad_pcb, HS96L03W2C03 DISPLAY.step, UI.kicad_sch]
2026-05-05 Continuated routing + fixing SSD1306 footprint
    [Educational-Board_MainBoard.kicad_pcb, sensors.kicad_sch]
2026-05-05 Routed most LEFT part of the board + modified button footprint + fixed some lables
    [Educational-Board_MainBoard.kicad_pcb, MCU.kicad_sch, UI.kicad_sch]
2026-05-05 Resized the board at the left part
    [Educational-Board_MainBoard.kicad_pcb]
2026-05-06 Added some exclusion from DRC + changed the min height for silkscreen
2026-05-06 Continued the routing
    [Educational-Board_MainBoard.kicad_pcb]
2026-05-06 Finished the routing: TODO fixing IMU
    [Educational-Board_MainBoard.kicad_pcb, MCU.kicad_sch]
2026-05-07 routing and silkscreen logo
    [Educational-Board_MainBoard.kicad_pcb, Educational-Board_MainBoard.kicad_sch, MCU.kicad_sch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]
2026-05-08 Added pullup to the joystick, Fixes #16
    [Educational-Board_MainBoard.kicad_pcb, sensors.kicad_sch]
2026-05-12 Added placeholders connectors for the Nucleo - TO ADD LCSC CODES
    [Educational-Board_MainBoard.kicad_pcb, MCU.kicad_sch]
2026-05-12 added version marking, generated all the production files, added last connector lcsc number
    [DG126-5.0-02P-12-00AH.STEP, Educational-Board_MainBoard.kicad_pcb, MCU.kicad_sch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]
2026-05-13 Changed the Revision Number on the whole project
    [Educational-Board_MainBoard.kicad_pcb, Educational-Board_MainBoard.kicad_sch, MCU.kicad_sch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]
2026-05-13 added missing 3d models
    [Educational-Board_MainBoard.kicad_pcb, WS2812-2020.STEP, usb-c.STEP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]
2026-05-15 Changed the sheets of the project
    [Educational-Board_MainBoard.kicad_pcb, Educational-Board_MainBoard.kicad_sch, sensors.kicad_sch]
2026-05-15 Added 3D models to the USB and on the LEDs
    [Educational-Board_MainBoard.kicad_pcb, UI.kicad_sch]
2026-06-29 Changed the Nucleo Symbol to add Arduino Names + Rotated a I2C jumper near the LCD
    [Educational-Board_MainBoard.kicad_pcb, MCU.kicad_sch]
